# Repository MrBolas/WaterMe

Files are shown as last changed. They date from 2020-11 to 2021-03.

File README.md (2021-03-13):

# WaterMe
Automatic plant watering project

*WaterMe* is a hobby project to design an automated green house. The porpuse to this effort is to allow for small outdoor spaces to grow vegetables or other nature derived products with the least effort has possible by humans (me), while confined to a city like environment. 

Ideally the system is designed to monitor and actuate on the Bio Products in order to sustain growth on a first instance, and optmize growth overtime with the application of software algorithms to the selection of the automated growth techniques.

The resulting system is designed to be modular and expandible over a larger scale. The application of this system  is designed to be free. 

The overall system is composed of several parts:
* Eletronic System
* Software Control System
* Hydric System

These systems all interface with each other with the shared porpuse of plant self sustain.

The system will accept as inputs environmental data and will use it for triggering certain actuation and display it over an interface for human monitor control.

The resulting actuation targets growth control through the usage of distinct control of environmental variables affecting the bio products.

On the basic version of the system it is expected certain input output control, altough this can change according to several design decisions.

#### Inputs/Outputs

##### Inputs/Sensors
Environmental inputs will be controlled through several sensors, these will monitor the following variables:

###### Generic Inputs
* Inside Green House Air Temperature
* Inside Green House Air Humidity
* Outside Green House Air Temperature
* Outside Gree House Air Humidity
* Soil Moisture
* Sunlight Exposure

###### Modular Specific Variables
* Soil Green House Temperature
* Soil Green House Humidity

##### Outputs/Actuation 
The resulting actuation is over disticnt eletronic devices in order to maintain desirable condition insisde the green house.
Available windows shall allow a controlable opening. This will serve several purposes. These could be temperature/humidity control of the entire green house or in raining conditions to allow watering with using controlled tapped water.
When rain is unavailable and soil humidity is bellow expected threshold the Water gauge control shall allow the watering of the plants trhough tapped water. The water gauge shall be connected to the standard 3 bar water source.

###### Generic Actuations
* Window control
* Water gauge

#### Modularity

The green house is designed taking expansion in mind but still trying to minimise cost.

Altough modules in the green house can be added to expand the ammount of available/cultivated/monitored soil some sensor apply to the specific container of the soil and other to the overall green house.

These is the explanation the previows seperation in the sensors listing.

## System Design

### Eletronic System Design
* This section needs a more specific description*

* The eletronic system has the porpuse of collecting sensor data and actuating uppon certain triggers.
The design has the mission of building a system with a micro controller that can interface with several sensors, allows comunication over WiFi or other wireless comunication and has a low power consumption to allow a sustainabel and renewable power source (ie solar panel).

The microcontroller requires a pinout compatible with the other sensors, wich translates into digital and analogical pins.

#### Stage 1

In the First stage the design shall have basic comunication with the network over Wifi.
Connection to Soil Moisture analog sensors and Temperature and Humidity Digital Sensors.
A power source from a solar panel.
A power buffer from a battery allowing normal functioning even when the solar panel has insufucient power production.
A housing that allows the protection of the circuits.

Current specification leads to:
- Microcontroler: https://www.amazon.es/gp/product/B079H29YZM/ref=ox_sc_act_title_5?smid=A1X7QLRQH87QA3&psc=1
- Solar Panel:  https://www.amazon.es/gp/product/B071D9MB7J/ref=ox_sc_act_title_1?smid=A1BHN76M75F32R&psc=1
- Battery bank: Power Bank 3200 mAh
- Soil Moisture Sensor: https://www.pantechsolutions.net/capacitive-soil-moisture-sensor-v2-0
- Temperature and Humidity Sensor: https://www.electrofun.pt/sensores-arduino/sensor-temperatura-humidade-dht11

Housing:
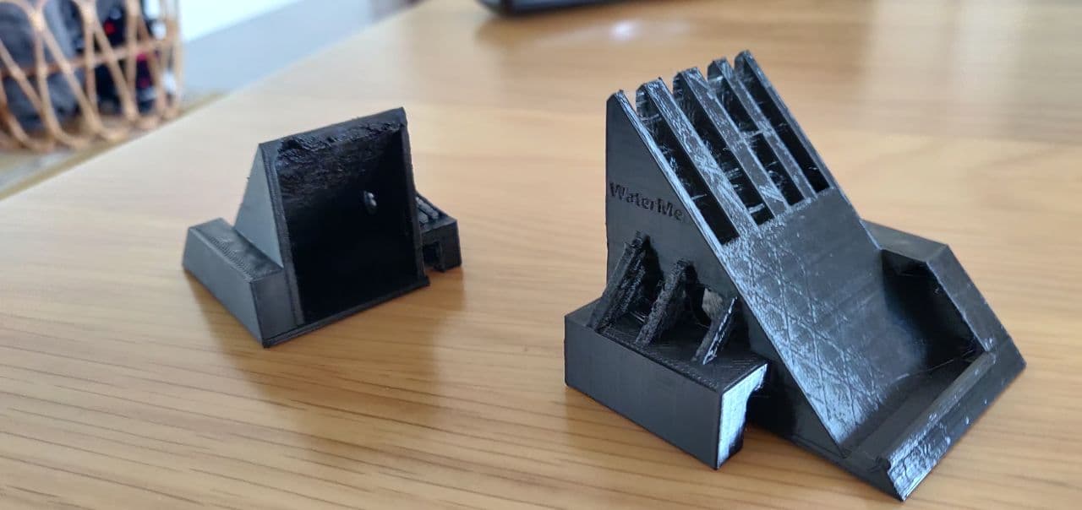
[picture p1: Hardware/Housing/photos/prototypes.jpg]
Housing mock print


### Software System Design

Currently the project infrastructure follows this architecture:
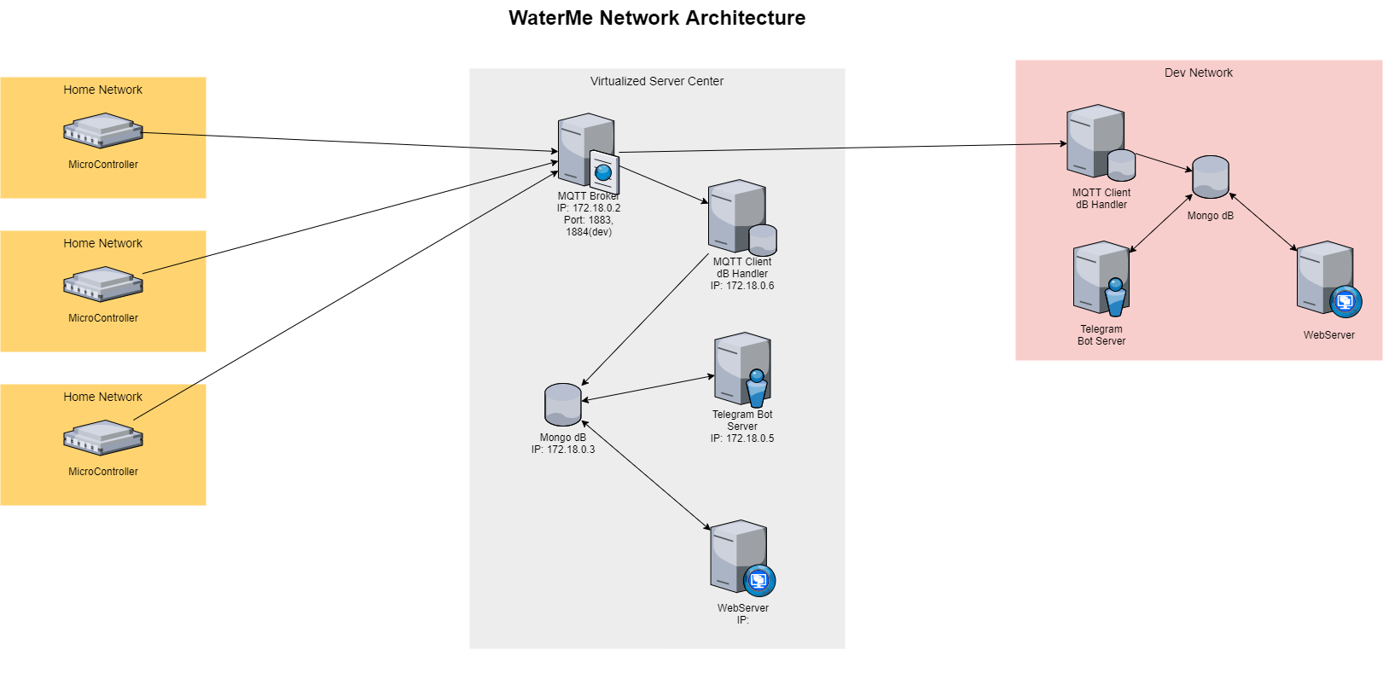
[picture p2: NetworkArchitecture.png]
Network Architecture


The Architecture is based on two seperate but complementary systems.
- Acquisition System
- Display System

Altough everything together makes a projects each system is complex enough to be a project itself.
In the following sections all explain these systems, how they are deployed, how they communicate and with what technologies they were built.

#### Acquisition System

##### Summary
The data accquisition system exists as a source of data for watering functions. Plants are delicate with their soil humidity, this needs to be carefully controlled. This acquisition relies on sensors and on external weather apis to determine the best conditions to water plants.

##### Functionality
Data is collected and identified by microcontroller id allowing a categorization of the data by microcontroller and consequently by location. The arquitecture used is an IOT protocol called Mosquitto (MQTT). This protocol uses a broker and any amount of clients connect to it. The protocol it self allows for any client to listen for messages on a specific "topic" like a subscription. In this case, all the microcontrollers are clients ( in an initial stage only send messages) and there is an extra MQTT client to parse and connect all the other clients to a database.

Every message follows a schema, containing the controller mac address, sensor type, and latest readings by the sensors.

```javascript
const microControllerMessage = {
    mac_address: {type: String, required: true},
    sensors: [{
        type: {type: String, required: true},
        readings: [{
            time: {type: String, required: true},
            value: {type: String, required: true}
        }]
    }],
};

```

##### Deployment

The system is deployed in a private dockerized network, where every machine is in docker.
For the data acquisition system the dockerized machines are:
- MQTT broker
- MQTT client/DB handler
- MongoDB

##### Communication
The communication in the acquisition system is heavily reliant on the MQTT protocol. Some rules were created above this protocol to better scale the system.
The rules are the creation of one main "topic" where every controller subscribes and reports its current state (if wake or not), and one individual "topic" by microcontroller minimizing redundant traffic in the network by having only two listeners to the specific "topics", the microcontroller and the MQTT DB handler.

Future work can allow by directional updates to the microcontrollers, altough right now, without actuators in the microcontrollers there is no apparent reason.

##### Technological stack
###### Arduino
Available in this [repo](https://github.com/MrBolas/WaterMe/tree/main/Software/Microcontroller).
C++, PIO Home
```C++
depending_libraries = 
	adafruit/Adafruit SSD1306@^2.4.0
	adafruit/Adafruit GFX Library@1.10.1
	adafruit/Adafruit BusIO@^1.6.0
	knolleary/PubSubClient@^2.8
	adafruit/DHT sensor library@^1.4.0
	adafruit/Adafruit Unified Sensor@^1.1.4
	malachi-iot/estdlib@^0.1.6
	bblanchon/ArduinoJson@^6.17.1
	arduino-libraries/NTPClient@^3.1.0
```

###### MQTT Client
Available in this [repo](https://github.com/MrBolas/WaterMeMQTTClient).
- Nodejs
- Javascript dependencies:
```Javascript
const mongoose = require('mongoose');
const mqtt = require('mqtt');
```

#### Display System
The display system is composed by a Telegram bot and a Web application.

This system relies on a decision engine. This is what allows the web application or the telegram bot to send notifications to water the plants based on the data.

This WaterMe Engine is available in this [repo](https://github.com/MrBolas/WaterMeSettings).

##### Telegram bot
Available in this [repo](https://github.com/MrBolas/WaterMeTelegramBot).

The idea behind a telegram is having a quick interface with notifications that is compatible with a high volume of devices, including wearable devices. The motivation is on an initial phase, where the watering process is not automated to at least send a notification to notify the user to manually water the plants.

This telegram bot is in active development and its served by a dockerized container.

###### Techonological Stack
- NodeJs
- Javascript dependencies:
```Javascript
const mongoose = require('mongoose');
const TeleBot = require('telebot');
const cron = require('node-cron');
```

##### Web application
Available in this [repo](https://github.com/MrBolas/WaterMeWeb).

< In active development >

### Hidric System Design (Future work)
*This section needs a more specific description*

*This section should be well thought out to calculate ammount of water gauge across the entire system. For this to work a base green house architecture should be assumed, using considering the several levels and water pressure loss across those levels.*

Points to think:
* Water pressure should not branch out from the base of the green house to the top. Pressure should be at it's peak from the water tap connection to the top of the green house and use gravity momentum to regain pressure when branching out. Not really sure if this is useful with a 3bar pressure and such a few branches. Could have positivo implication when considering scalability.
* Scalability should vary vertically or on the ground level? Seems like it should have a first level branch in each vertical shelf in the green house.

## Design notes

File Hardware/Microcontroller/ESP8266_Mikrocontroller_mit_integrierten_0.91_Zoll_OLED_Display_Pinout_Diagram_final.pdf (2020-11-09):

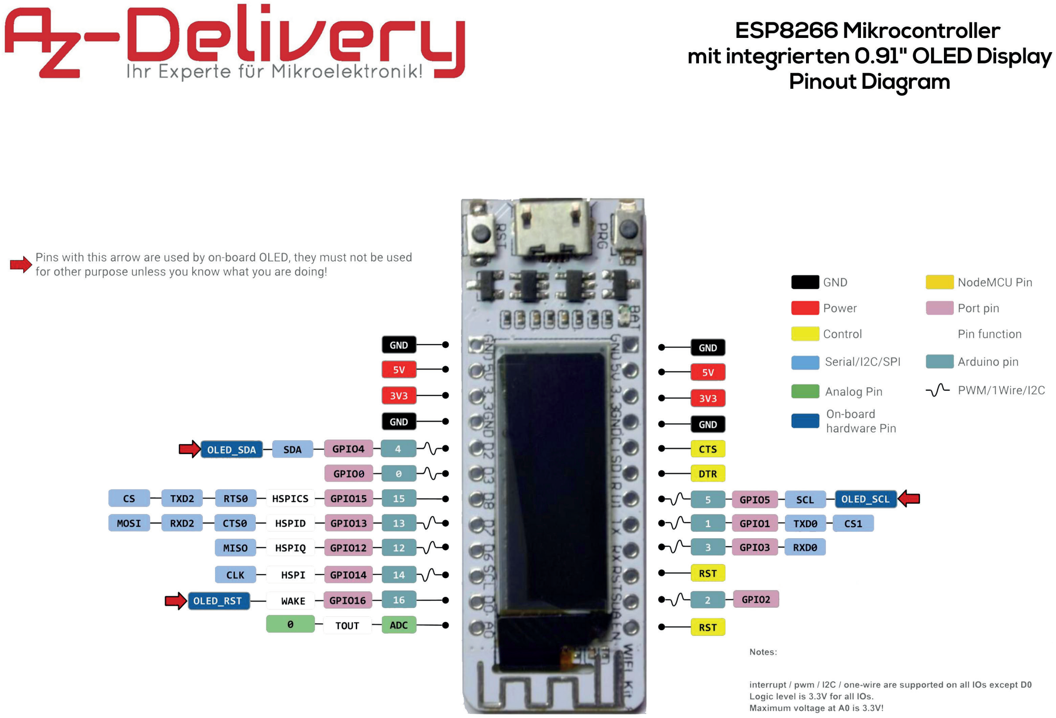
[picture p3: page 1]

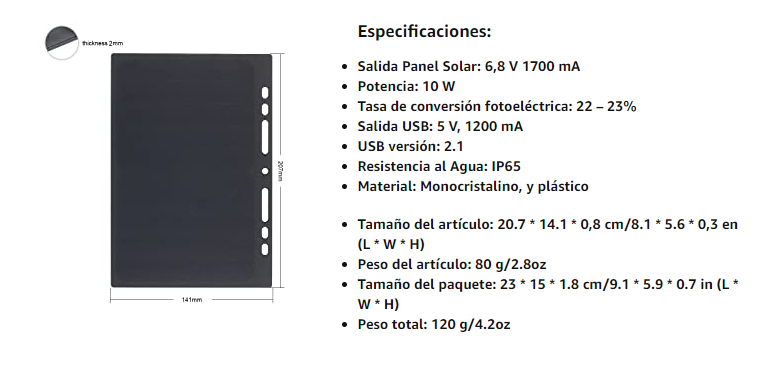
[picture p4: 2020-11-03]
Hardware/SolarPanel/Specifications.PNG

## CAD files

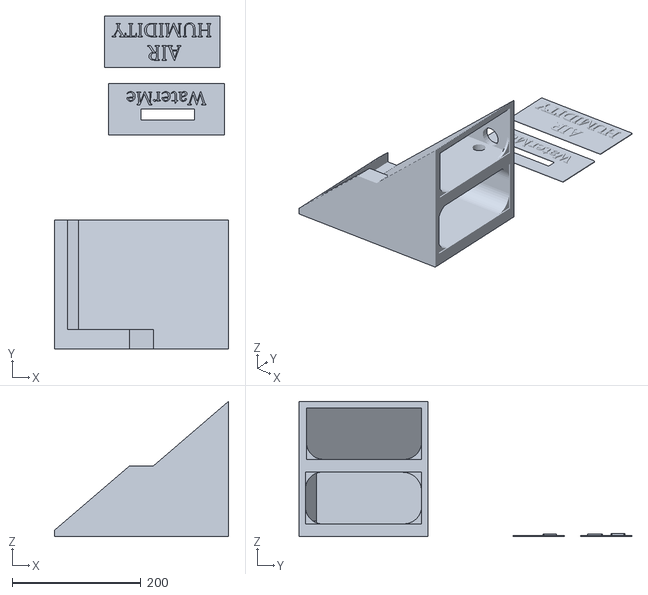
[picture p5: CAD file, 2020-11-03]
Hardware/Housing/3D Files/waterMe prototype_1_3.stl
270.0 x 516.2 x 210.0

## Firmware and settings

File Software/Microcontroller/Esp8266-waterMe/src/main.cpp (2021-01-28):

#include <SPI.h>
#include <Wire.h>
#include <DHT.h>
#include <time.h>
#include <NTPClient.h>
#include <WiFiUdp.h>
#include <Arduino.h>
#include <ArduinoJson.h>
#include <ESP8266WiFi.h>
#include <PubSubClient.h>
#include <Adafruit_GFX.h>
#include <Adafruit_SSD1306.h>
#include <SoilMoistureSensor/SoilMoistureSensor.h>

#define DHTTYPE DHT22   // DHT 22

#define DHTPOWERPIN 2
#define DHT1PIN 13    
#define DHT2PIN 3    

#define SMS1POWERPIN 15
#define SMS2POWERPIN 12
#define SMS3POWERPIN 0
#define SMS4POWERPIN 14
#define SMSREADPIN A0
#define SMSVOLTAGE 3.3

#define mqtt_server "94.62.211.190"
//#define mqtt_user "your_username"
//#define mqtt_password "your_password"

#define MicroControllerID WiFi.macAddress()

#define DEEP_SLEEP_TIMER 3e8  //microseconds 5 minutes
#define WAKE_UP_TIME 5e3     //milliseconds

#define main_topic "WaterMe"

Adafruit_SSD1306 OLED = Adafruit_SSD1306(128, 32, &Wire);

//Setup JSON
DynamicJsonDocument doc(2048);
char serialized_json[1024];

DHT dht1(DHT1PIN, DHTTYPE);
DHT dht2(DHT2PIN, DHTTYPE);

//Flower Pot1
SoilMoistureSensor SMS1(SMS1POWERPIN, SMSREADPIN, SMSVOLTAGE);
SoilMoistureSensor SMS2(SMS2POWERPIN, SMSREADPIN, SMSVOLTAGE);

//Flower Pot 2
SoilMoistureSensor SMS3(SMS3POWERPIN, SMSREADPIN, SMSVOLTAGE);
SoilMoistureSensor SMS4(SMS4POWERPIN, SMSREADPIN, SMSVOLTAGE);

const char* ssid = "The Internet";
const char* password = "Papaya0721";

WiFiClient espClient;
PubSubClient client(espClient);
const long utcOffsetInSeconds = 3600;
WiFiUDP ntpUDP;
NTPClient timeClient(ntpUDP, "pool.ntp.org", utcOffsetInSeconds);

int dht_temp_1 = 0;
int dht_hum_1 = 0;

int dht_temp_2 = 0;
int dht_hum_2 = 0;

float SMS1_value = NAN;
float SMS2_value = NAN;
float SMS3_value = NAN;
float SMS4_value = NAN;

void updateOLED()
{
  OLED.clearDisplay();
  OLED.setCursor(0,0);
  
  //IP / connection Status
  OLED.print(WiFi.isConnected() ? WiFi.localIP().toString() : "Disconnected");

  //Temperature and Humidity
  OLED.setCursor(80,0);
  OLED.print("T:");
  int reported_temp = dht_temp_1 != 0 ? dht_temp_2 != 0 ? (dht_temp_1+dht_temp_2)/2 : dht_temp_1 : 0;
  int reported_hum = dht_hum_1 != 0 ? dht_hum_2 != 0 ? (dht_hum_1+dht_hum_2)/2 : dht_hum_1 : 0;

  if (reported_temp == 0)
  {
    OLED.print("- ");
  }else{
    OLED.print(reported_temp);
  }

  OLED.print("H:");
  
  if (reported_hum == 0)
  {
    OLED.println("- ");
  }else{
    OLED.println(reported_hum);
  }

  //Mac Adress
  OLED.println(MicroControllerID);

  // Horizontal Moisture Bars for Pot 1
  OLED.drawRect(0,16,50,8,1);
  OLED.fillRect(0,16,50*(SMS1_value/SMSVOLTAGE),8,1);
  OLED.setCursor(52,16);
  OLED.print("Pot1");
  OLED.drawRect(78,16,50,8,1);
  OLED.fillRect(128-78*(SMS2_value/SMSVOLTAGE),16,128-78*(SMS2_value/SMSVOLTAGE),8,1);
  
  // Horizontal Moisture Bars for Pot 2
  OLED.drawRect(0,24,50,8,1);
  OLED.fillRect(0,24,50*(SMS3_value/SMSVOLTAGE),8,1);
  OLED.setCursor(52,24);
  OLED.print("Pot2");
  OLED.drawRect(78,24,50,8,1);
  OLED.fillRect(128-78*(SMS4_value/SMSVOLTAGE),24,128-78*(SMS4_value/SMSVOLTAGE),8,1);

  OLED.display();
}

void readingVerification()
{
  if (dht_temp_1 > 120)
  {
    dht_temp_1 = 0;
  }
  
  if (dht_temp_2 > 120)
  {
    dht_temp_2 = 0;
  }

  if (dht_hum_1 > 120)
  {
    dht_hum_1 = 0;
  }

  if (dht_hum_2 > 120)
  {
    dht_hum_2 = 0;
  }
}

void setup_wifi() {
  delay(10);
  // We start by connecting to a WiFi network
  Serial.println();
  Serial.print("Connecting to ");
  Serial.println(ssid);

  WiFi.begin(ssid, password);

  while (WiFi.status() != WL_CONNECTED) {
    delay(500);
    Serial.print(".");
  }
  
  Serial.println("");
  Serial.println("WiFi connected");
  Serial.println("IP address: ");
  Serial.println(WiFi.localIP());
 
  updateOLED();
}

void setDHTPowerPin(bool state)
{
  digitalWrite(DHTPOWERPIN, state);
}

void reconnect() {
  // Loop until we're reconnected
  while (!client.connected()) {
    Serial.print("Attempting MQTT connection...");
    // Attempt to connect
    // If you do not want to use a username and password, change next line to
     if (client.connect("client")) {
    //if (client.connect("ESP8266Client", mqtt_user, mqtt_password)) {
      Serial.println("connected to Brooker");
    } else {
      Serial.print("failed, rc=");
      Serial.print(client.state());
      Serial.println(" try again in 5 seconds");
      // Wait 5 seconds before retrying
      delay(5000);
    }
  }
}

void goToSleep()
{
  OLED.clearDisplay();
  OLED.display();

  setDHTPowerPin(LOW);

  //enter deep sleep in microseconds
  ESP.deepSleep(DEEP_SLEEP_TIMER); 
}

void publish_MQTT()
{
  serializeJson(doc, serialized_json);
  Serial.println(serialized_json);
  client.publish(MicroControllerID.c_str(), serialized_json);
  delay(250); // create delay so other clients can cope with data flow
}

bool validReading(int reading)
{
  if (reading > 120 || reading < -10)
  {
    return false;
  }
  return true;
}

void setup() {
  //Setup Serial
  Serial.begin(115200);

  OLED.begin(SSD1306_SWITCHCAPVCC, 0x3C); // Address 0x3C for 128x32
  OLED.setCursor(0,0);
  OLED.setTextSize(1);
  OLED.setTextColor(SSD1306_WHITE);
  updateOLED();

  //Setup Wifi
  setup_wifi();
  client.setServer(mqtt_server, 1883);

  // DHT Power Pin Mode
  pinMode(DHTPOWERPIN, OUTPUT);
  digitalWrite(DHTPOWERPIN, LOW);

  // Turn ON both SMS
  pinMode(SMS1POWERPIN, OUTPUT);
  digitalWrite(SMS1POWERPIN, LOW);
  
  pinMode(SMS2POWERPIN, OUTPUT);
  digitalWrite(SMS2POWERPIN, LOW);

  pinMode(SMS3POWERPIN, OUTPUT);
  digitalWrite(SMS3POWERPIN, LOW);
  
  pinMode(SMS4POWERPIN, OUTPUT);
  digitalWrite(SMS4POWERPIN, LOW);


}

void loop() {
  
  if (!client.connected()) {
    reconnect();
  }
  client.loop();

  //Sends wake notification to main topic
  client.publish(main_topic, MicroControllerID.c_str());

  unsigned long time = millis();
  
  // Turn on DHT sensors
  setDHTPowerPin(HIGH);
  delay(500);

  //initializa DHT22 sensors
  dht1.begin();
  dht2.begin();

  // Delay to initialize DHT22 sensors
  delay(1000);

  // Acquire Sensor information
  SMS1.turnPowerOn();
  delay(250);
  SMS1_value = SMS1.readSensorVoltage();
  SMS1.turnPowerOff();

  SMS2.turnPowerOn();
  delay(250);
  SMS2_value = SMS2.readSensorVoltage();
  SMS2.turnPowerOff();

  SMS3.turnPowerOn();
  delay(250);
  SMS3_value = SMS3.readSensorVoltage();
  SMS3.turnPowerOff();

  SMS4.turnPowerOn();
  delay(250);
  SMS4_value = SMS4.readSensorVoltage();
  SMS4.turnPowerOff();

  dht_temp_1 = dht1.readTemperature();
  dht_hum_1 = dht1.readHumidity();

  dht_temp_2 = dht2.readTemperature();
  dht_hum_2 = dht2.readHumidity();

  //Reading Verification
  readingVerification();

  //Update OLED
  updateOLED();

  // Update Serial and MQTT Broker
  Serial.print(timeClient.getFormattedTime());
  Serial.println((" -> DHT_TEMP_1/"+String(dht_temp_1)).c_str());
  
  Serial.print(timeClient.getFormattedTime());
  Serial.println((" -> DHT_HUM_1/"+String(dht_hum_1)).c_str());

  Serial.print(timeClient.getFormattedTime());
  Serial.println((" -> DHT_TEMP_2/"+String(dht_temp_2)).c_str());
  
  Serial.print(timeClient.getFormattedTime());
  Serial.println((" -> DHT_HUM_2/"+String(dht_hum_2)).c_str());

  Serial.print(timeClient.getFormattedTime());
  Serial.println((" -> SMS1/"+String(SMS1_value)).c_str());
  
  Serial.print(timeClient.getFormattedTime());
  Serial.println((" -> SMS2/"+String(SMS2_value)).c_str());

  Serial.print(timeClient.getFormattedTime());
  Serial.println((" -> SMS3/"+String(SMS3_value)).c_str());
  
  Serial.print(timeClient.getFormattedTime());
  Serial.println((" -> SMS4/"+String(SMS4_value)).c_str());

  // Build JSON
  // Serializes and punlishes JSON over MQTT
  timeClient.update();
  doc["mac_address"] = MicroControllerID;
  doc["time"] = timeClient.getEpochTime();

  if (validReading(dht_temp_1))
  {
    doc["type"] = "DHT1_temp";
    doc["value"] = dht_temp_1;
    publish_MQTT();
  }

  if (validReading(dht_hum_1))
  {
    doc["type"] = "DHT1_hum";
    doc["value"] = dht_hum_1;
    publish_MQTT();
  }

  if (validReading(dht_temp_2))
  {
    doc["type"] = "DHT2_temp";
    doc["value"] = dht_temp_2;
    publish_MQTT();
  }

  if (validReading(dht_hum_2))
  {
    doc["type"] = "DHT2_hum";
    doc["value"] = dht_hum_2;
    publish_MQTT();
  }

  doc["type"] = "SMS1";
  doc["value"] = SMS1_value;
  publish_MQTT();

  doc["type"] = "SMS2";
  doc["value"] = SMS2_value;
  publish_MQTT();

  doc["type"] = "SMS3";
  doc["value"] = SMS3_value;
  publish_MQTT();

  doc["type"] = "SMS4";
  doc["value"] = SMS4_value;
  publish_MQTT();

/*
  if ((SMS1.beingWatered() 
  || SMS2.beingWatered() 
  || SMS3.beingWatered() 
  || SMS4.beingWatered()) 
  && time == 0) // testing for now. Should not use deepsleep cycle
  */
  if(false)
  {
    time = millis(); 
  }else if(time > WAKE_UP_TIME){
    time = 0;
    goToSleep();
  }
  
}

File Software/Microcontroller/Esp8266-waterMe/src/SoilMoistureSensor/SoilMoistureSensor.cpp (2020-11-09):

#include <Arduino.h>
#include <SoilMoistureSensor/SoilMoistureSensor.h>

SoilMoistureSensor::SoilMoistureSensor(int power_pin_index, int sensor_pin_index, int sensor_power_voltage)
{
    this->PowerPin.pin_index = power_pin_index;
    this->PowerPin.role = Power;
    this->PowerPin.voltage = sensor_power_voltage;
    pinMode(this->PowerPin.pin_index, OUTPUT);
    digitalWrite(this->PowerPin.pin_index, LOW);
    this->SensorPin.power_state = false;
    
    this->SensorPin.pin_index = sensor_pin_index;
    this->SensorPin.role = Reader;
    this->SensorPin.power_state = false;
    this->SensorPin.voltage = 0;
}

SoilMoistureSensor::~SoilMoistureSensor(){}

bool SoilMoistureSensor::beingWatered()
{
    return this->previousSensorReading < this->sensorReading;
}

float SoilMoistureSensor::readSensorVoltage()
{
    this->previousSensorReading = sensorReading;
    this->sensorReading = float(float(analogRead(SensorPin.pin_index))/1023.0)*PowerPin.voltage;
    return sensorReading;
}

float SoilMoistureSensor::getWaterVolume()
{
  float voltage = readSensorVoltage();
  return ((1.0/voltage)*slope)+intercept; // calc of theta_v (vol. water content)
}

float SoilMoistureSensor::getSensorPercentage()
{
    return this->readSensorVoltage()/this->getPowerPinMaxVoltage();
}

int SoilMoistureSensor::getPowerPinIndex()
{
    return this->PowerPin.pin_index;
}

bool SoilMoistureSensor::getPowerPinPowerState()
{
    return this-PowerPin.power_state;
}
float SoilMoistureSensor::getPowerPinMaxVoltage()
{
    return this->PowerPin.power_state ? this->PowerPin.voltage : 0;
}

int SoilMoistureSensor::getSensorPinIndex()
{
    return this->SensorPin.pin_index;
}

void SoilMoistureSensor::turnPowerOn()
{
    pinMode(this->PowerPin.pin_index, OUTPUT);
    digitalWrite(this->PowerPin.pin_index, HIGH);
}

void SoilMoistureSensor::turnPowerOff()
{
    pinMode(this->PowerPin.pin_index, OUTPUT);
    digitalWrite(this->PowerPin.pin_index, LOW);
}

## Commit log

2020-11-03 Added housing prototype 1.3
    [waterMe prototype_1_3.stl]
2020-11-06 Fixed .gitignore to reject node_modules
    [main.cpp]
2020-11-06 Fixed .gitignore Changed MQTT_server folder name MQTT_client is now connected to a test broker MicroController is now connected to test broker
    [main.cpp]
2020-11-09 Changed OLED display Added SMS sensors
2020-11-09 OLED Redesign. Double bar per POT
    [main.cpp]
2020-11-09 OLED display will now show: Average temperature Average Humidity Soil Moisture for 4 sensors
2020-11-09 Fiex deep sleep timer in the ESP8266 Corrected the MQTT topics in the client
    [main.cpp]
2020-11-10 Added JSON format for MQTT messages. Modified nodeJS MQTT client. Messages are now bigger than public brokers allow.
    [main.cpp]
2020-11-11 Added custom MQTT broker
    [main.cpp]
2020-11-22 Moved models to an outer npm package Changed the SMS value sent from the Mcontroller to a Voltage value
2021-01-28 Changed power control to the DHT sensors to save power
